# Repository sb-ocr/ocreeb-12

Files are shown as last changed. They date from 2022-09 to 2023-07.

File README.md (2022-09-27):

# Ocreeb12

Watch the build video ↓

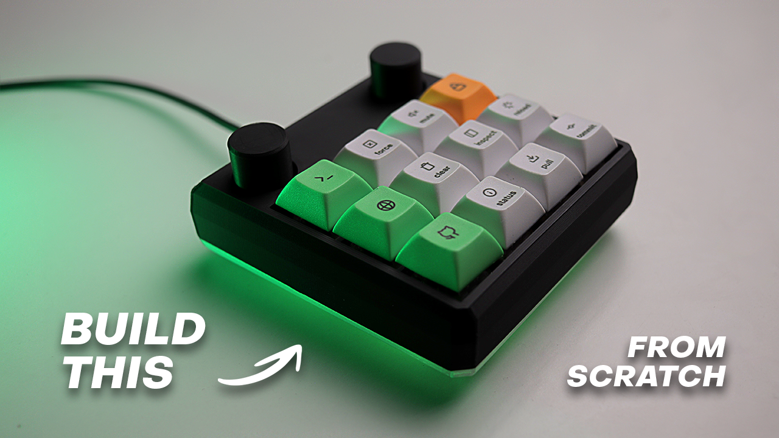
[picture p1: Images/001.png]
[](https://youtu.be/P_oSLBZABGA)

This is a 12 key macro keypad with 2 rotary encoders, custom keycaps and under-glow RGB. 
Ocreeb is running KMK firmware on the Adafruit KB2040.

Order the PCB: [pcbway.com](https://www.pcbway.com/project/shareproject/DIY_Mechanical_Macro_Keypad_Ocreeb_24300065.html)

Build instructions: [instructables.com](https://www.instructables.com/DIY-Mechanical-Macro-Keypad-Ocreeb/)

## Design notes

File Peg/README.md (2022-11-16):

Ocreeb 12 Logo

This a user guide for Ocreeb 12 with [Peg](https://peg.software/) compatible [firmware](/Peg/Firmware).
Ocreeb is a 12 key Programmable macro keypad with 2 rotary encoders and underglow RGB, running KMK firmware on the Adafruit KB2040. 

Checkout the build :hammer_and_wrench: [video](https://youtu.be/P_oSLBZABGA)

# Quick Start

## Step 1 

Hold down the top right button on Ocreeb and plug it into your computer, you can release it when you see a mass storage device `CIRCUITPY` mounted. This is the first step to customize your device. :warning: If you don't see the device mounted, you won't be able to access the code or change the key mapping using the flashing software.

Step 1

## Step 2

Download and install the [Peg software](https://peg.software/). A feature-rich flashing solution for configuration through the GUI. Your system may ask you when you first launch to allow access to mass storage devices :warning: This is required for Peg to work.

## Step 3

You should be able to see Ocreeb recognized by Peg in the upper right corner. Out of the box, the macropad is assigned a default keymap.
You can program the keys and encoder from the available keycodes or create your own custom codes | [instructions below ↓](#custom-keycodes)

Step 3

## Step 4

Once you are happy with the keymap, click on `SAVE MAP` and wait for the `SAFE TO UNPLUG` message.
You can now unplug and replug the device to hide the mass storage drive and use it normally.

To recover access, repeat [Step 1](#step-1) and relaunch Peg if it didn't pickup the device right away.

<br>

# Peg Software[^1]

:warning: [0.9 Beta Warning](https://peg.software/docs/#09-beta-warning)

## Keymap

The Keymap view is your main view. If you want to change what any key does on your keyboard you make that change here.

To map a key you can do it in 1 of 2 ways. You can drag it from below and drop it on the key you want to change, or you can click on the key you want to change and then click on the key you want to change it to below.

## Encoder

The Encoder view is just like the Keymap view just with only your encoder available to map.

:warning: The right side encoder on this version of Ocreeb is reserved to the RGB Hue control, you can only program the encoder's switch in the Keymap view.

## Make Custom

Make Custom is a more advanced section of the Peg client, it allows you to add onto your keycode selection. The peg client supports any keycode you could want to do but the client may not let you make it inside the UI. In the client you can make simple macros, eg: push one key and type out "Hello my name is Cole". To do more advanced keycodes supported by KMK | [instructions below ↓](#custom-keycodes) | or to backup your custom keycodes you can click the `Export` button in the Custom Keycodes tab. This will first let you copy all of your current keycodes for safe keeping and give you a template to edit to make more.
<br>

[^1]: Source: [Peg Client Docs](https://peg.software/docs/Peg_Client/)

# Custom Keycodes

You can make custom keycodes in this JSON format to be able to add them in Peg Flashing Software.

```json
[
  {
    "code":"KC.LT(1, KC.ENT)",
    "display":"L1-ENT",
    "keybinding":"",
    "canHaveSub":false,
    "canHaveSubNumber":false,
    "subNumber":0,
    "Description":"Pushes layer 1 if held and enter if tapped"
  }
]
```
Get started faster by copying the content of this [collection](https://github.com/sb-ocr/ocreeb-12/blob/main/Peg/Firmware/custom-keycodes.json).
Press the `Show import Keycodes` Button and paste in your the json array, click the `Import` button. Now you should be able to see your new keycodes under the `Custom Codes Tab` in your keymap.

Most macros in the example collection are created using one or a combination of these 2 sequences:

1. `send_string()`

It can be used to send any standard English alphabet character, and an assortment of other "standard" keyboard keys (return, space, exclamation points, etc.)

```json
[
  {
    "code": "send_string('git add .')",
    "display": "G AD",
    "keybinding": "",
    "canHaveSub": false,
    "canHaveSubNumber": false,
    "subNumber": 0,
    "Description": "git add . (Send String)"
  }
]
```
2. `simple_key_sequence()`

This is best suited for shortcuts that require multiple modifier keys (⌘, Ctrl, Alt, Shift...)

Nested modifiers are sent to the host in the order in which they are nested. In the example below, this macro will produce the following behavior: `⌘ + control + q` `wait for 400ms then` `Escape`

```json
[
  {
    "code": "simple_key_sequence([KC.LCTRL(KC.LCMD(KC.Q)), KC.MACRO_SLEEP_MS(400), KC.ESCAPE])",
    "display": "LOCK",
    "keybinding": "",
    "canHaveSub": false,
    "canHaveSubNumber": false,
    "subNumber": 0,
    "Description": "Lock Screen (macOS)"
  }
]
```
Here is a full list of possible keys in the [KMK Firmware Docs](https://github.com/KMKfw/kmk_firmware/blob/master/docs/en/keycodes.md) to make you own macros.
<br>

# Layers[^2]

There is a total of 8 possible layout layers in this version of Ocreeb. You can access them from the right side of the window `0 to 7`, in the keymap and encoder views.

When starting out, care should be taken when working with layers, since it's possible to lock yourself to a layer with no way of returning to the base layer short of unplugging your keyboard. This is especially easy to do when using the `KC.TO()` keycode, which deactivates all other layers in the stack.

Some helpful guidelines to keep in mind as you design your layers:

Only reference higher-numbered layers from a given layer
Leave keys as `KC.TRNS` in higher layers when they would overlap with a layer-switch

Further Reading:
- [Layers in KMK](https://github.com/KMKfw/kmk_firmware/blob/master/docs/en/layers.md)
- [Modtap in KMK](https://github.com/KMKfw/kmk_firmware/blob/master/docs/en/modtap.md)

[^2]: Source: [KMK Docs](https://github.com/KMKfw/kmk_firmware/blob/master/docs/en/layers.md)
<br>

# Advanced

If you want to extend the functionality of your macropad beyond what is possible in the Peg software or if you want to manage your keymap directly in the code. You can check this [firmware version](/Firmware) described in the [build video](https://youtu.be/P_oSLBZABGA). This version removes compatibility with Peg and it'is recommended if you want go the code only route.

Build instructions: 
- [Instructables](https://www.instructables.com/DIY-Mechanical-Macro-Keypad-Ocreeb/)
- [Hackster](https://www.hackster.io/ocr_lab/diy-mechanical-macro-keypad-ocreeb-76d00c)

<br>

# Questions

I will do my best to answer any questions regarding the build or configuration of this project.

You can DM with your questions here [LinkTree](https://linktr.ee/salimbenbouz)

Thank you for checking out Ocreeb!

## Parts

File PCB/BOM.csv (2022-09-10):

Qty | Value | Digikey | Device | Package | Parts | Description
2 |  | PEC11R-4215F-S0024-ND | ELECTROMECH_ENCODER_PLUS_SWITCH_BOURNS_PEC11 | ELECTROMECH_PEC11+SWITCH | SW1, SW2 | Rotary Encoder with Built-In Switch
12 |  | 1655-1360-1-ND | DIODESOD-123 | MICROBUILDER_SOD-123 | D1, D2, D3, D4, D5, D6, D7, D8, D9, D10, D11, D12 | Diode
4 | 0.1uF | 276-CL10B104KB8NNNLCT-ND | 0.1UF-0603-25V-(+80/-20%) | 603 | C1, C2, C3, C4 | 0.1µF ceramic capacitors
1 | 10K | RMCF0805JG10K0CT-ND | R-US_R0805 | R0805 | R1 | RESISTOR, American symbol
1 | 74HCT1G125DBV | 296-49526-1-ND | 74AHC1G125DBV | SOT23-5 | IC1 | Single Bus Buffer Gate with 3-State Output
12 | CHERRY_MX | 1528-4952-ND | CHERRY_MX | CHERRY_MX | S1, S2, S3, S4, S5, S6, S7, S8, S9, S10, S11, S12 | Cherry keymodule MX
1 | KB2040 | 1528-5302-ND | KB2040 | KB2040_SMD | U1 | Adafruit KB2040
4 | WS2812B5050 | 1528-1104-ND | WS2812B5050 | WS2812B | LED1, LED2, LED3, LED4 | Neopixels

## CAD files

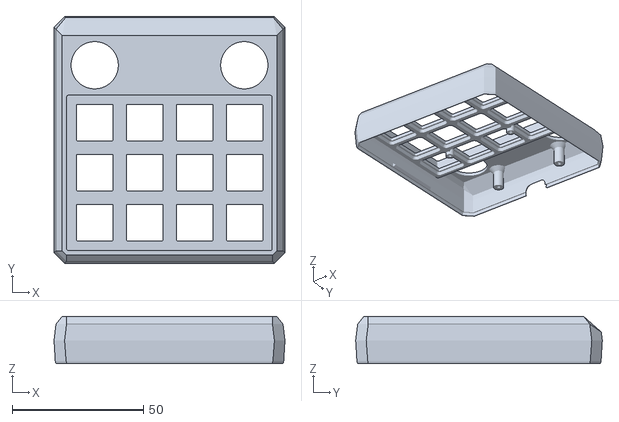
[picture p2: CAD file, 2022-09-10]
STLs/Case Top.stl
88.0 x 94.0 x 18.0

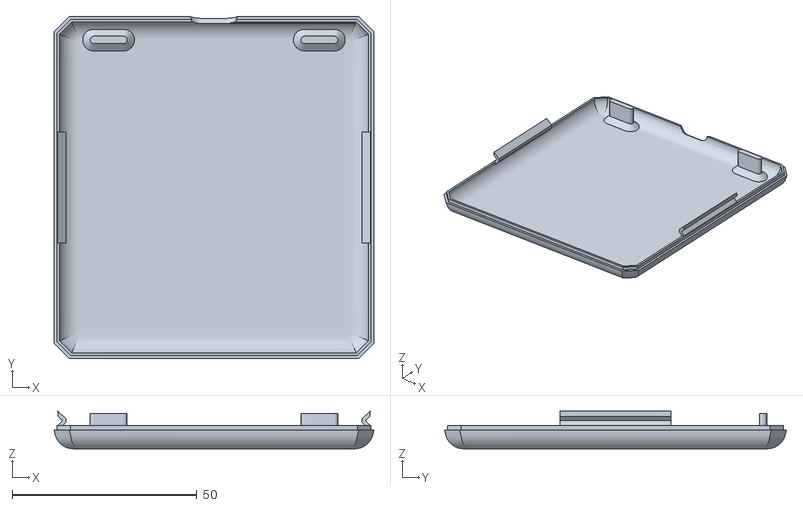
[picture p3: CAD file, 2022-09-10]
STLs/Case Bottom.stl
86.6 x 92.5 x 10.2

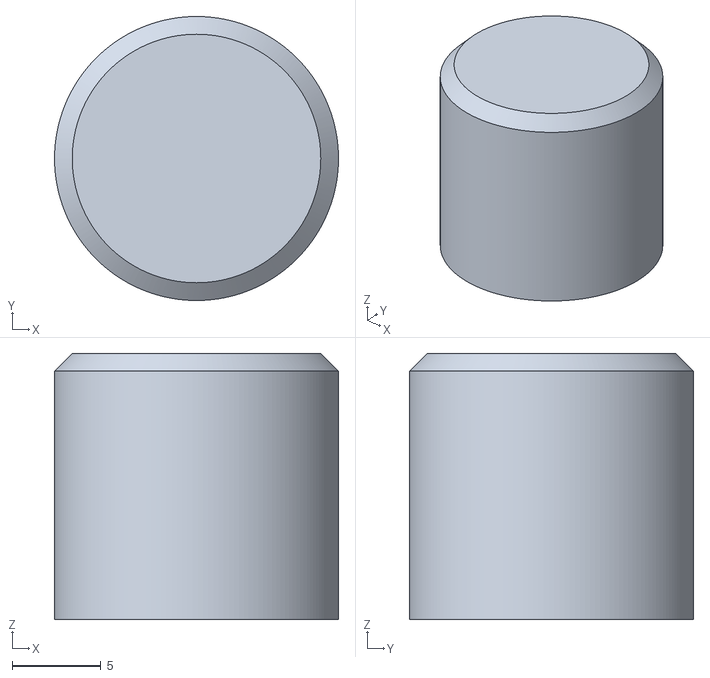
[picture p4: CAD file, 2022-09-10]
STLs/Knob.stl
16.0 x 16.0 x 15.0

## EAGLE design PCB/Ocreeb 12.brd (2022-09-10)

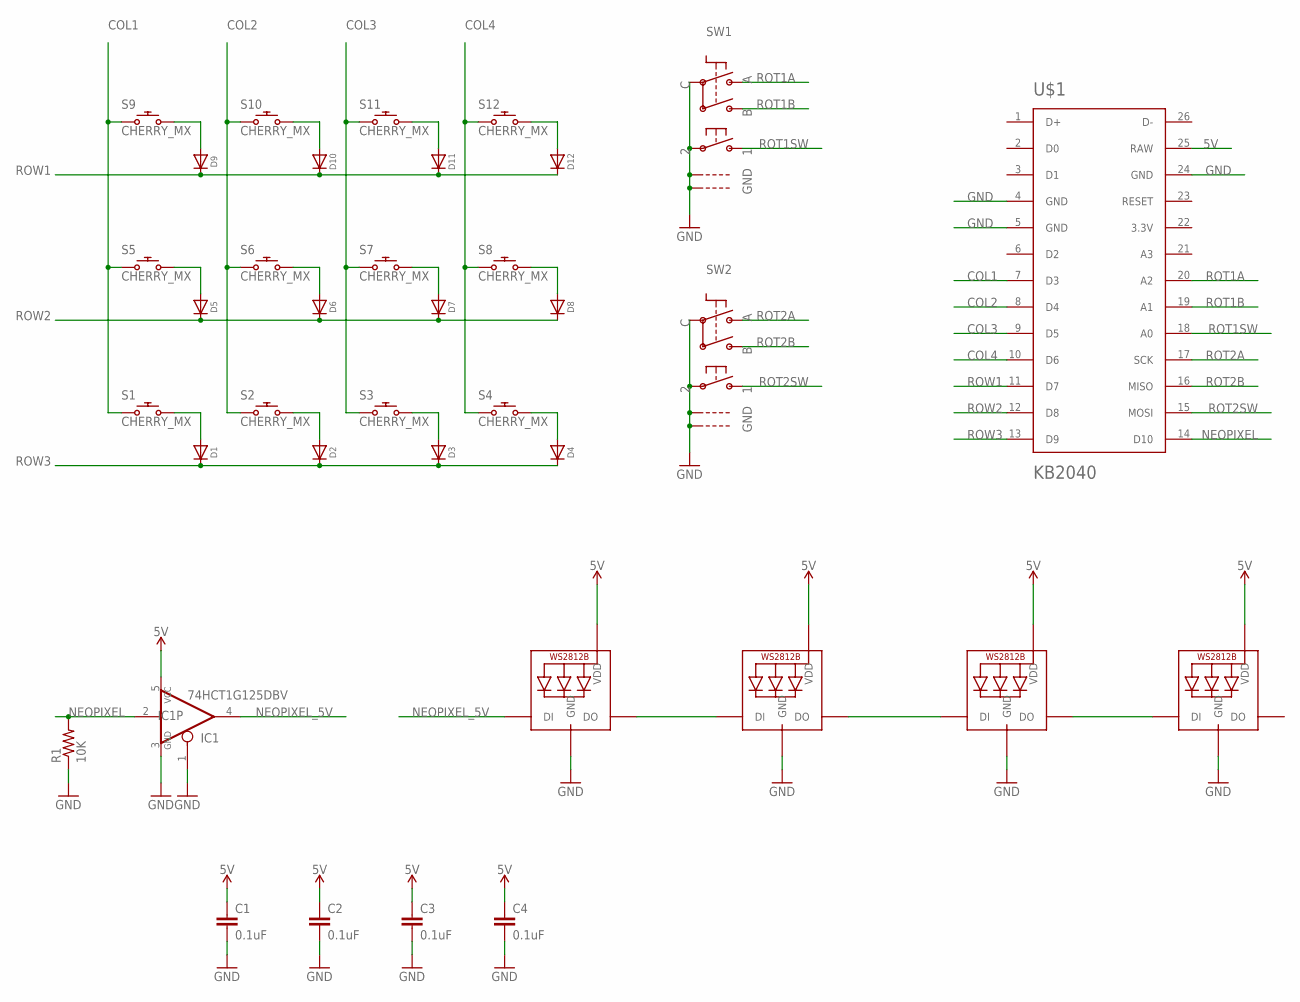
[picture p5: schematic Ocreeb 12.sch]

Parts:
C1, C2, C3, C4: 0.1uF; 0603
D1, D2, D3, D4, D5, D6, D7, D8, D9, D10, D11, D12: MICROBUILDER_DIODESOD-123; MICROBUILDER_SOD-123
IC1: 74HCT1G125DBV; SOT23-5
LED1, LED2, LED3, LED4: WS2812B5050; WS2812B
R1: 10K; R0805
S1, S2, S3, S4, S5, S6, S7, S8, S9, S10, S11, S12: CHERRY_MX
SW1, SW2: ADAFRUIT_ELECTROMECH_ENCODER_PLUS_SWITCH_BOURNS_P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; ADAFRUIT_ELECTROMECH_PEC11+SWITCH
U$1: KB2040; KB2040_SMD

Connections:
5V: C1.1, C2.1, C3.1, C4.1, IC1.5 (VCC), LED1.1-VDD (VDD), LED2.1-VDD (VDD), LED3.1-VDD (VDD), LED4.1-VDD (VDD), U$1.25 (RAW)
COL1: S1.S1 (1), S5.S1 (1), S9.S1 (1), U$1.7 (D3)
COL2: S2.S1 (1), S6.S1 (1), S10.S1 (1), U$1.8 (D4)
COL3: S3.S1 (1), S7.S1 (1), S11.S1 (1), U$1.9 (D5)
COL4: S4.S1 (1), S8.S1 (1), S12.S1 (1), U$1.10 (D6)
GND: C1.2, C2.2, C3.2, C4.2, IC1.1 (OE), IC1.3 (GND), LED1.3-GND (GND), LED2.3-GND (GND), LED3.3-GND (GND), LED4.3-GND (GND), R1.1, SW1.P$2, SW1.P$C, SW1.P$GND1, SW1.P$GND2, SW2.P$2, SW2.P$C, SW2.P$GND1, SW2.P$GND2, U$1.4 (GND), U$1.5 (GND), U$1.24 (GND)
unnamed: LED1.2-DOUT (DO), LED2.4-DIN (DI)
unnamed: LED2.2-DOUT (DO), LED3.4-DIN (DI)
unnamed: LED3.2-DOUT (DO), LED4.4-DIN (DI)
unnamed: D5.A, S5.S2 (2)
unnamed: D6.A, S6.S2 (2)
unnamed: D8.A, S8.S2 (2)
unnamed: D7.A, S7.S2 (2)
unnamed: D2.A, S2.S2 (2)
unnamed: D3.A, S3.S2 (2)
unnamed: D1.A, S1.S2 (2)
unnamed: D4.A, S4.S2 (2)
unnamed: D10.A, S10.S2 (2)
unnamed: D12.A, S12.S2 (2)
unnamed: D11.A, S11.S2 (2)
unnamed: D9.A, S9.S2 (2)
NEOPIXEL: IC1.2 (I), R1.2, U$1.14 (D10)
NEOPIXEL_5V: IC1.4 (O), LED1.4-DIN (DI)
ROT1A: SW1.P$A, U$1.20 (A2)
ROT1B: SW1.P$B, U$1.19 (A1)
ROT1SW: SW1.P$1, U$1.18 (A0)
ROT2A: SW2.P$A, U$1.17 (SCK)
ROT2B: SW2.P$B, U$1.16 (MISO)
ROT2SW: SW2.P$1, U$1.15 (MOSI)
ROW1: D9.C, D10.C, D11.C, D12.C, U$1.11 (D7)
ROW2: D5.C, D6.C, D7.C, D8.C, U$1.12 (D8)
ROW3: D1.C, D2.C, D3.C, D4.C, U$1.13 (D9)

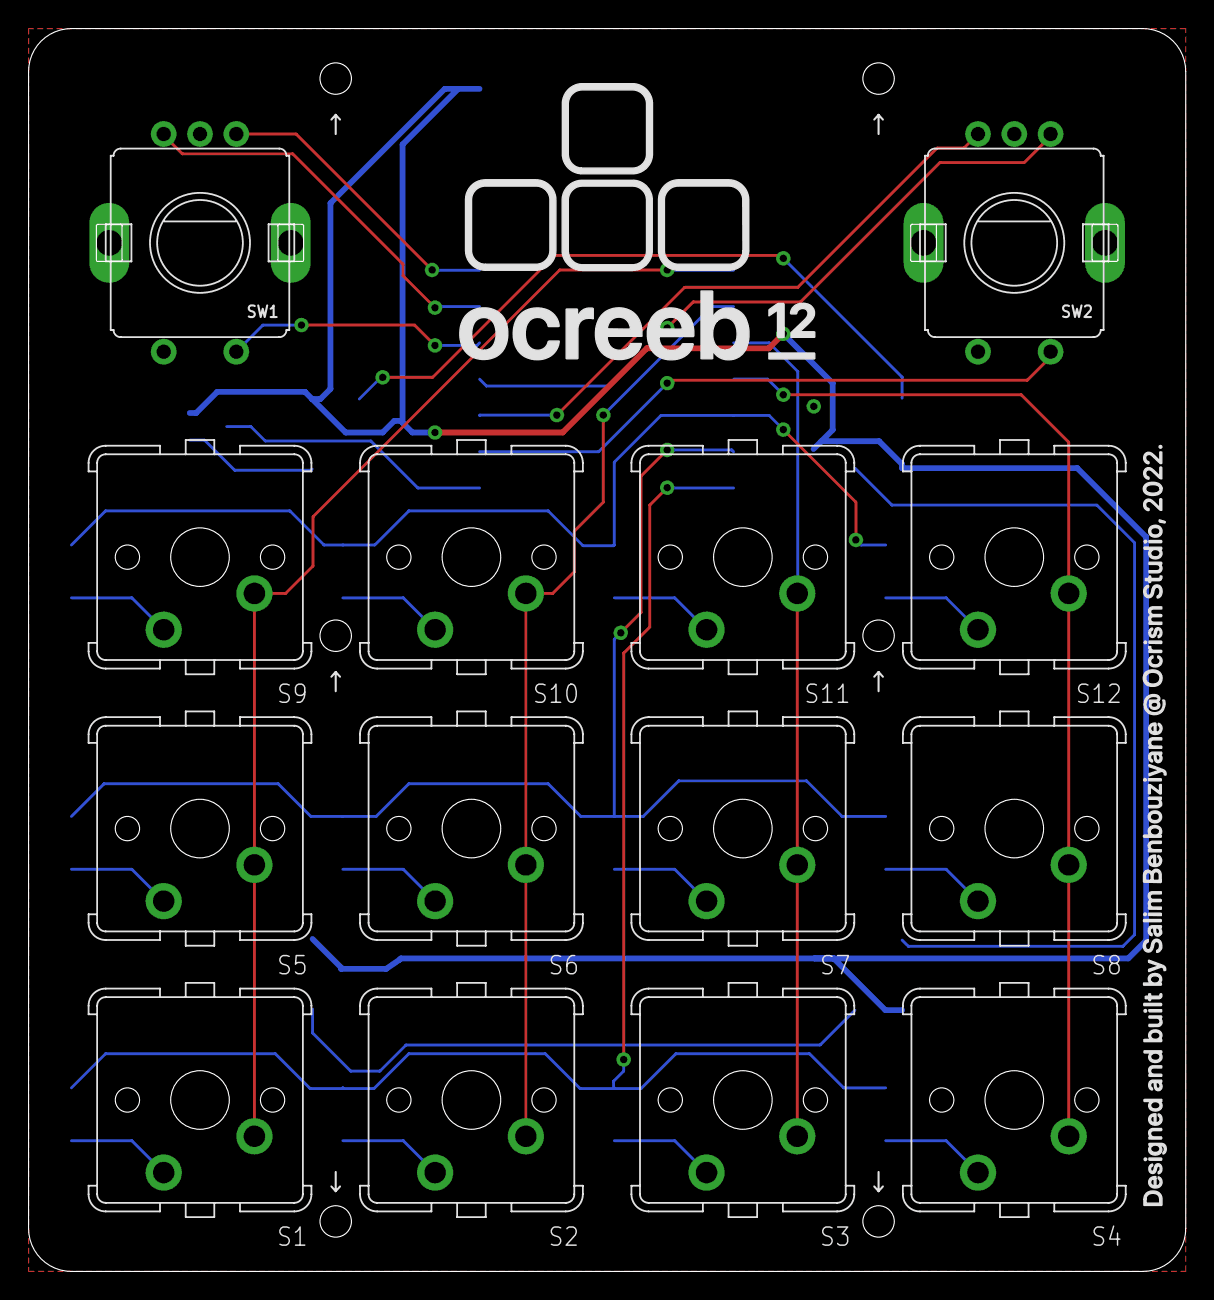
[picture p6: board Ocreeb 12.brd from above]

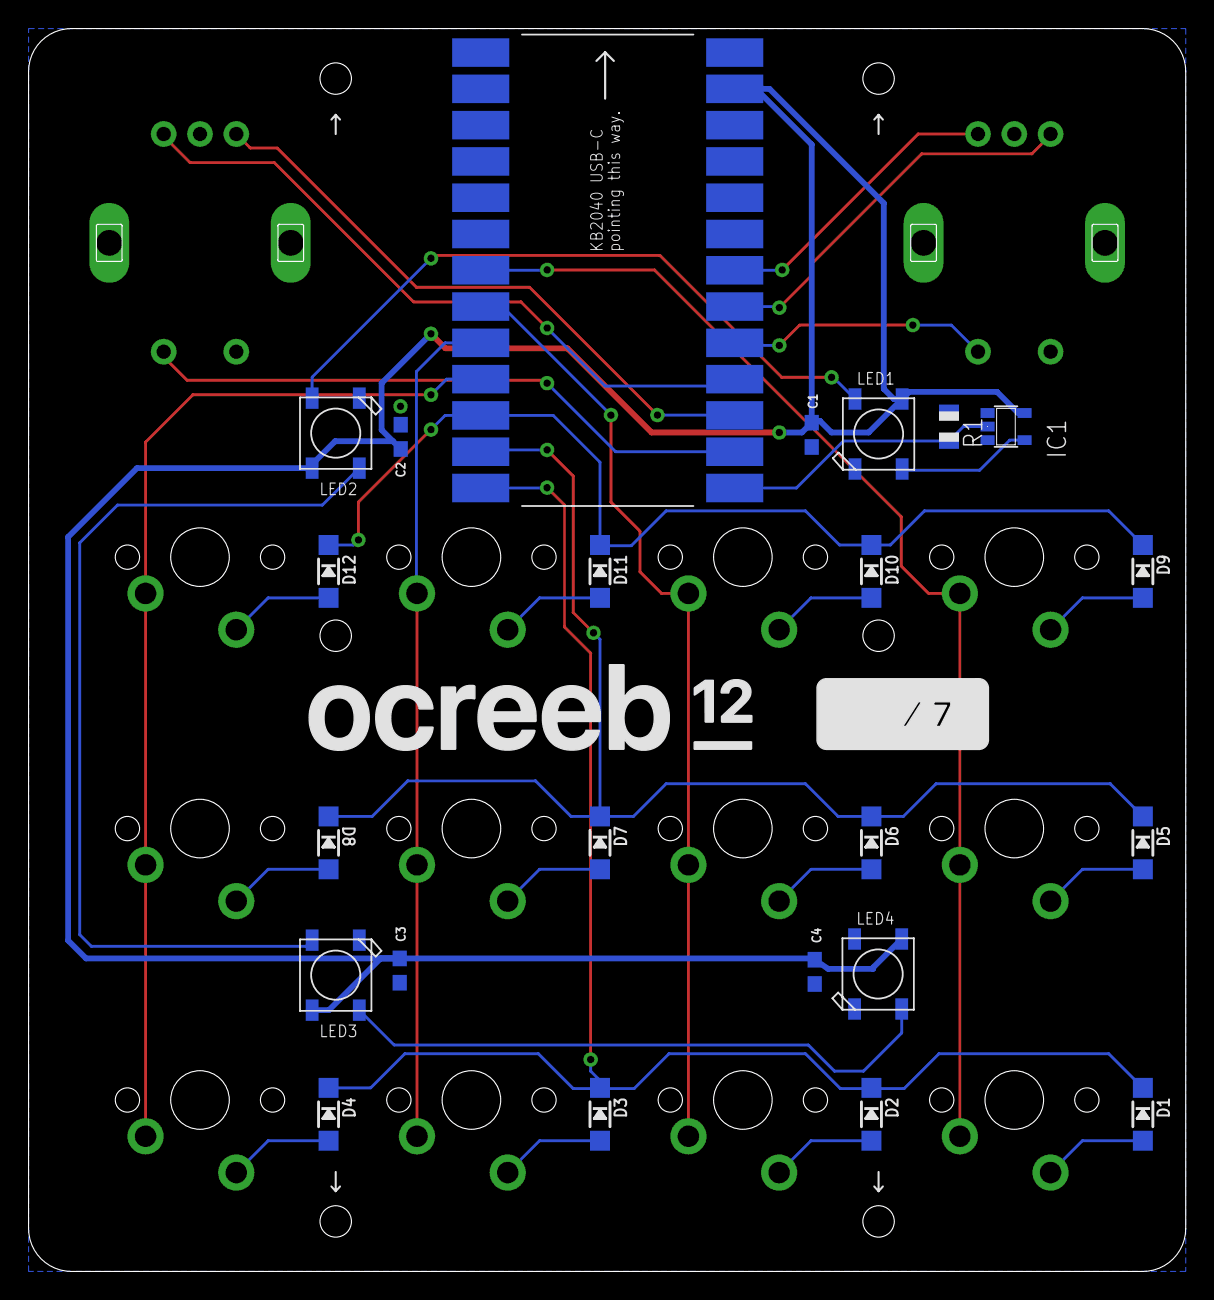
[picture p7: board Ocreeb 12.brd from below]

Board: 2 copper layers, 81.0 x 87.0 mm, 37 parts (23 on the bottom side), 32 nets.

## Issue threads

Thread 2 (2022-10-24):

Feasibility of adding more buttons + profile switching

ItaloKnox, 2022-10-24:
Hello! I got your video recommended on YouTube and the bonus midi capabilities really sold me to build one myself. I have a decent grasp of Python, got a 3D printer coming and some Arduino experience. Just a few days ago, I started using micropython on a couple ESP8266 boards, so I'm still figuring out how to handle the interfacing between Python and a board.

If possible, I hope you can help me squash a few questions before I can start the build:

1- Adafruit products are hard to come by in Brazil, so I decided to import a few generic RP2040 boards from AliExpress, since the ESP8266 isn't compatible with Circuitpython. [These](https://circuitpython.org/board/vcc_gnd_yd_rp2040/), and the 16mb model to be exact. Other than the bigger footprint of the board, double-checking the pins and the adjustments necessary to the PCB, is there anything else I should be on the lookout?

2- Like the title said, I want to expand the board to add more buttons. Maybe a 4x4 or 4x5 grid. I'm having some trouble understanding the switch matrix in the code, the macros rows are self-explanatory (I believe I just need to add the new buttons to each row), but I'm having trouble figuring out if I need to set up more pins for the extra buttons.

3- Third and final, the reason why I need more buttons is that I plan on using these to facilitate my Blender workflow and DAW (both with midi and keyboard shortcuts - but not at the same time). Of course, both software don't share the same shortcuts, and using the pad outside of them would also be pretty much useless. How feasible would it be to set up profile switching to a new extra button and then change all macros based on that?

I'm looking forward to seeing more videos from you on YouTube. Best of luck!

sb-ocr, 2022-10-25:
Thank you for checking out the project.

1- As you said the footprint of the board you chose isn't compatible with this PCB. So if you're going to design a new one for it to fit, it should be fine. The other thing is the castellated pads, this board doesn't have them and to solder it directly to a PCB you would need to use use some shortened headers for example.

2- Yes you need more pins to add more switches in your matrix but usually it's in a grid configuration. If we take the example you provided 4 x 5. You can setup this as 4 columns and 5 rows (or the other way around) for a total of 9 pins to detect 20 keys, the diodes will prevents the current to go backwards (and causing ghost keystrokes). After you initialize the keyboard class in KMK you supply the row pins, the columns pins and the diodes orientation. The matrix scanner isn't the only one available in KMK you can checkout [this part](https://github.com/KMKfw/kmk_firmware/blob/master/docs/en/scanners.md) of the documentation for more options on how to add other hardware.

3- Yes, this concept is called [Layers](https://github.com/KMKfw/kmk_firmware/blob/master/docs/en/layers.md) in keyboard firmware. You can jump between them in different ways: Toggle, Momentary hold or even [Tap dance](https://github.com/KMKfw/kmk_firmware/blob/master/docs/en/tapdance.md) (that's what I used to toggle the midi layer in this project)

I hope this answered all your questions. Best of luck!

Closed 2022-10-25.

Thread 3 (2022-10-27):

Library Files

RichardTHF, 2022-10-27:
Hi,

Do you the lbr Library Files for the KB2040 and KB2040 MacroPad? Trying to modify the PCB for the more common and cheap RP2040-Zero? I can only find their board and schematic on the Adafruit GitHub and Eagle won't me modify the PCB without them.

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

:)

sb-ocr, 2022-11-11:
Hi,
I just exported the libraries used in the project and added the file to the PCB folder.
Let me know if it works for you.

Closed 2022-11-11.

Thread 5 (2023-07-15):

Peg firmware does not disable USB mount

crysxd, 2023-07-15:
While building the Ocreeb 12 I did encounter an issue with the Peg firmware: the USB drive is not disabled when the keyboard is plugged in without any buttons pressed.

The issue seems that this method is not defined, causing the `boot.py` to crash and never reach the code to disable the USB drive
https://github.com/sb-ocr/ocreeb-12/blob/dfa3336f30952da78e412d684a4ae4413014fd59/Peg/Firmware/boot.py#L11

I did remove this line for me and it solved the issue, everything works as expected (only mounted when top right button is pressed), but I'm not sure what the implications of removing this line are.

Just wanted to document the issue :)

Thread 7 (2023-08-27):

WS2812B Neopixel doesn't work

GeoffreyOlivier, 2023-08-27:
Hello, with my friend we have build two keyboard, but the neopixel doesn't work.

There issue with keyboard azerty ?

thanks

sb-ocr, 2023-08-27:
No, it's probably the soldering of the Neopixels. Try to reflow them again

inlag, 2023-09-25:
@GeoffreyOlivier
I'm not sure if I can help, but I had the same problem.
In my case I needed to update the CircuitPython firmware from adafruit to version 8.2.6

Closed 2023-08-27.

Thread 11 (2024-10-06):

Microcontroller Semi-functional

crownmikey, 2024-10-06:
I got my rotary encoder (singular, left) to work but my LEDS and key presses **do not work.** Peg software recognizes my board and I can map it. Currently using CircuitPython 9.1.4. No switches are soldered yet since im debugging.

1) I think I saw that the right encoder is for RGB so that could be why the right encoder is not functional atm
     1a) When I press the right encoder, my code stops
2) When I load my board the below image is was shows up in Mu command window.

Is there an error here that I don't understand? Or if not any other guesses on what I should investigate next? I've checked all my soldering connections with multimeter and physical examination.

Thanks!

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

crownmikey, 2024-10-11:
Issue resolved. My level shifter didnt have a solid connection, reflowed and it works.

Closed 2024-10-11.

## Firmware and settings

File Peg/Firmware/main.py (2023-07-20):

from kb import KMKKeyboard
from kmk.keys import KC
from kmk.modules.layers import Layers
from kmk.modules.modtap import ModTap
from kmk.hid import HIDModes
from kmk.handlers.sequences import send_string
import supervisor
keyboard = KMKKeyboard()
modtap = ModTap()
layers_ext = Layers()
keyboard.modules.append(layers_ext)
keyboard.modules.append(modtap)
# codeblock
keyboard.debug_enabled = True
from kmk.extensions.media_keys import MediaKeys
from kmk.handlers.sequences import simple_key_sequence
from kmk.modules.encoder import EncoderHandler
from kmk.extensions.RGB import RGB
import microcontroller

rgb = RGB(
    pixel_pin=keyboard.rgb_pixel_pin, 
    num_pixels=keyboard.rgb_num_pixel, 
    hue_default=microcontroller.nvm[0]
)

def on_move_do(state):
    if state is not None and state['direction'] == -1:
        rgb.decrease_hue()
    else:
        rgb.increase_hue()
    microcontroller.nvm[0] = rgb.hue

encoder_handler = EncoderHandler()
encoder_handler.pins = ((keyboard.rgb_encoder_a, keyboard.rgb_encoder_b, None, False),)
encoder_handler.on_move_do = lambda x, y, state: on_move_do(state)

encoder_handler.map =   [ ((KC.RGB_HUD, KC.RGB_HUI, KC.RGB_TOG),), ]
keyboard.extensions.append(MediaKeys())
keyboard.extensions.append(rgb)
keyboard.extensions.append(encoder_handler)
# codeblock
keyboard.modules = [layers_ext, modtap]
# encodercount
# 1
# encodercount
# keymap
keyboard.keymap = [ [KC.AUDIO_MUTE,KC.RGB_TOG,KC.KP_7,KC.KP_8,KC.KP_9,KC.KP_ASTERISK,KC.KP_4,KC.KP_5,KC.KP_6,KC.KP_MINUS,KC.KP_1,KC.KP_2,KC.KP_3,KC.KP_PLUS,KC.AUDIO_VOL_DOWN,KC.AUDIO_VOL_UP], 
[KC.NO,KC.NO,KC.NO,KC.NO,KC.NO,KC.NO,KC.NO,KC.NO,KC.NO,KC.NO,KC.NO,KC.NO,KC.NO,KC.NO,KC.NO,KC.NO], 
[KC.NO,KC.NO,KC.NO,KC.NO,KC.NO,KC.NO,KC.NO,KC.NO,KC.NO,KC.NO,KC.NO,KC.NO,KC.NO,KC.NO,KC.NO,KC.NO], 
[KC.NO,KC.NO,KC.NO,KC.NO,KC.NO,KC.NO,KC.NO,KC.NO,KC.NO,KC.NO,KC.NO,KC.NO,KC.NO,KC.NO,KC.NO,KC.NO], 
[KC.NO,KC.NO,KC.NO,KC.NO,KC.NO,KC.NO,KC.NO,KC.NO,KC.NO,KC.NO,KC.NO,KC.NO,KC.NO,KC.NO,KC.NO,KC.NO], 
[KC.NO,KC.NO,KC.NO,KC.NO,KC.NO,KC.NO,KC.NO,KC.NO,KC.NO,KC.NO,KC.NO,KC.NO,KC.NO,KC.NO,KC.NO,KC.NO], 
[KC.NO,KC.NO,KC.NO,KC.NO,KC.NO,KC.NO,KC.NO,KC.NO,KC.NO,KC.NO,KC.NO,KC.NO,KC.NO,KC.NO,KC.NO,KC.NO], 
[KC.NO,KC.NO,KC.NO,KC.NO,KC.NO,KC.NO,KC.NO,KC.NO,KC.NO,KC.NO,KC.NO,KC.NO,KC.NO,KC.NO,KC.NO,KC.NO] ] 
# keymap
if __name__ == '__main__': 
    keyboard.go(hid_type=HIDModes.USB)

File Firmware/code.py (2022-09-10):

print("Starting")

import board

from kmk.kmk_keyboard import KMKKeyboard
from kmk.keys import KC
from kmk.matrix import DiodeOrientation
from kmk.handlers.sequences import send_string, simple_key_sequence
from kmk.modules.layers import Layers
from kmk.modules.encoder import EncoderHandler
from kmk.modules.tapdance import TapDance
from kmk.extensions.RGB import RGB
from midi import Midi


# KEYTBOARD SETUP
layers = Layers()
keyboard = KMKKeyboard()
encoders = EncoderHandler()
tapdance = TapDance()
tapdance.tap_time = 250
keyboard.modules = [layers, encoders, tapdance]

# SWITCH MATRIX
keyboard.col_pins = (board.D3, board.D4, board.D5, board.D6)
keyboard.row_pins = (board.D7, board.D8, board.D9)
keyboard.diode_orientation = DiodeOrientation.COL2ROW

# ENCODERS
encoders.pins = ((board.A2, board.A1, board.A0, False), (board.SCK, board.MISO, board.MOSI, False),)

# EXTENSIONS
rgb_ext = RGB(pixel_pin = board.D10, num_pixels=4, hue_default=100)
midi_ext = Midi()
keyboard.extensions.append(rgb_ext)
keyboard.extensions.append(midi_ext)
keyboard.debug_enabled = False

# MACROS ROW 1
GIT = simple_key_sequence([KC.LCMD(KC.LALT(KC.LSFT(KC.T))), KC.MACRO_SLEEP_MS(1000), KC.LCTRL(KC.U), send_string('open https://github.com'), KC.ENTER])
G_STATUS = simple_key_sequence([KC.LCMD(KC.LALT(KC.LSFT(KC.T))), KC.MACRO_SLEEP_MS(1000), KC.LCTRL(KC.U), send_string('git status'), KC.ENTER])
G_PULL = simple_key_sequence([KC.LCMD(KC.LALT(KC.LSFT(KC.T))), KC.MACRO_SLEEP_MS(1000), KC.LCTRL(KC.U), send_string('git fetch origin'), KC.ENTER])
G_COMMIT = simple_key_sequence([KC.LCMD(KC.LALT(KC.LSFT(KC.T))), KC.MACRO_SLEEP_MS(1000), KC.LCTRL(KC.U), send_string('git commit -m ""'), KC.LEFT])

# MACROS ROW 2
BROWSER = simple_key_sequence([KC.LCMD(KC.LALT(KC.LSFT(KC.T))), KC.MACRO_SLEEP_MS(1000), KC.LCTRL(KC.U), send_string('open https://ocrism.studio'), KC.ENTER])
CLEAR = simple_key_sequence([KC.LCMD(KC.LSFT(KC.BSPC))])
INSPECT = simple_key_sequence([KC.LCMD(KC.LALT(KC.I))])
HARD_RELOAD = simple_key_sequence([KC.LCMD(KC.LSFT(KC.R))])

# MACROS ROW 3
TERMINAL = simple_key_sequence([KC.LCMD(KC.LALT(KC.LSFT(KC.T))), KC.LCTRL(KC.U)])
FORCE_QUIT = simple_key_sequence([KC.LCMD(KC.LALT(KC.ESCAPE))])
MUTE = KC.MUTE
LOCK = simple_key_sequence([KC.LCTRL(KC.LCMD(KC.Q)), KC.MACRO_SLEEP_MS(400), KC.ESCAPE])


_______ = KC.TRNS
xxxxxxx = KC.NO

# LAYER SWITCHING TAP DANCE
TD_LYRS = KC.TD(LOCK, KC.MO(1), xxxxxxx, KC.TO(2))
MIDI_OUT = KC.TD(KC.MIDI(70), xxxxxxx, xxxxxxx, KC.TO(0))

# array of default MIDI notes
# midi_notes = [60, 61, 62, 63, 64, 65, 66, 67, 68, 69, 70, 71, 72, 73, 74, 75]

# KEYMAPS

keyboard.keymap = [
    # MACROS
    [
        TERMINAL,   FORCE_QUIT,     KC.MUTE,    TD_LYRS,
        BROWSER,    CLEAR,          INSPECT,    HARD_RELOAD,
        GIT,    G_STATUS,       G_PULL,     G_COMMIT,
    ],
    # RGB CTL
    [
        xxxxxxx,    xxxxxxx,            xxxxxxx,                xxxxxxx,
        xxxxxxx,    KC.RGB_MODE_SWIRL,  KC.RGB_MODE_KNIGHT,     KC.RGB_MODE_BREATHE_RAINBOW,
        xxxxxxx,    KC.RGB_MODE_PLAIN,  KC.RGB_MODE_BREATHE,    KC.RGB_MODE_RAINBOW,
    ],
    # MIDI
    [
        KC.MIDI(30),    KC.MIDI(69),      KC.MIDI(70),       MIDI_OUT,
        KC.MIDI(67),    KC.MIDI(66),      KC.MIDI(65),       KC.MIDI(64),
        KC.MIDI(60),    KC.MIDI(61),      KC.MIDI(62),       KC.MIDI(63),
    ]
]

encoders.map = [    ((KC.VOLD, KC.VOLU, KC.MUTE),           (KC.RGB_VAD,    KC.RGB_VAI,     KC.RGB_TOG)),   # MACROS
                    ((KC.RGB_AND, KC.RGB_ANI, xxxxxxx),     (KC.RGB_HUD,    KC.RGB_HUI,     _______   )),   # RGB CTL
                    ((KC.VOLD, KC.VOLU, KC.MUTE),           (KC.RGB_VAD,    KC.RGB_VAI,     KC.RGB_TOG)),   # MIDI
                ]


if __name__ == '__main__':
    keyboard.go()

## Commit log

2022-09-27 Build Instructable and PCB Way link
2022-10-20 bugfix encoder
    I've got the problem, that i could use just one binding for both encoder-buttons.
    Encoders-Buttons got the same id. This commit will fix the problem
2022-11-16 RGB encoder extension
2023-07-15 Restore RGB color after reboot
    [main.py]

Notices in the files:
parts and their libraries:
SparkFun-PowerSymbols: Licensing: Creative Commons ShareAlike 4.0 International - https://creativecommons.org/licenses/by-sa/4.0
